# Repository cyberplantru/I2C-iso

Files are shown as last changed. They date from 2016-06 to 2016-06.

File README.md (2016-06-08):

EC Reader
##CyberPlant I2C *iso* Mini

The I2C *iso* Mini v3.0 are hot swappable digital isolators with nonlatching, bidirectional communication channels that
are compatible with I2C interfaces. This eliminates the need for
splitting I2C signals into separate transmit and receive signals
for use with standalone optocouplers. The I2C *iso* Mini provides two bidirectional channels, supporting a complete isolated I2C interface.

##Features:
- Regulated 3.3 V or 5 V output
- Up to 500 mW output power
- Bidirectional I2C communication
- input-output pull up 4k7
- Can use as Shield for Arduino Pro Mini
- PCB Size : 33.02 mm×17.78 mm

## Applications
- Isolated sensor interfaces
- Isolated I2C, SMBus, or PMBus interfaces
- Multilevel I2C interfaces
- Power supplies
- Networking
- RS-232/RS-422/RS-485 transceivers

#### Regulated 3.3 V or 5 V output

By default supply voltage set to output 5V. For use other mode need to cut copper wire on layer top and use jumper as switch

pH to I2C
 


## Isolation of sensors

Use to eliminate electrical noise. The I2Ciso recommended to when reading pH and Conductivity together. Compatible with [pH Mini](https://github.com/cyberplantru/pH-Mini-v30-sample-code) and [EC Mini](EC-Mini-v30-Sample-Code). 

pH to I2C

----------

### Package include:

-     1 x I2C iso Mini v3.0
-     2 x 12 PLS connectors
-     2 x 4 angle PLS
-     1 x jumper

----------

### Documentation:

- [Hardware](https://github.com/cyberplantru/I2C-iso/)
- [link to CyberPlant](http://www.cyber-plant.com).

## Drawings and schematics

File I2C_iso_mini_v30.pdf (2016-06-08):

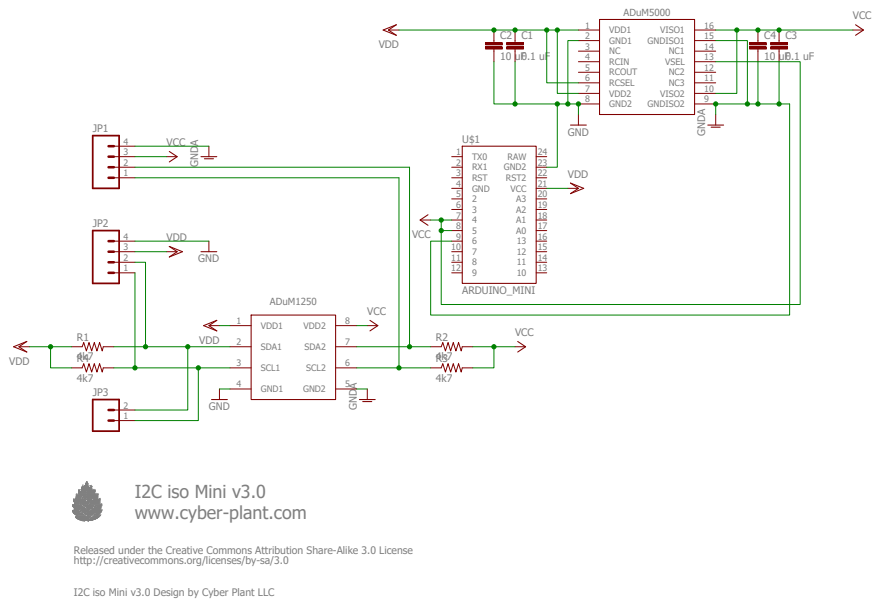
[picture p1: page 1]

I2C iso Mini v3.0
www.cyber-plant.com

Released under the Creative Commons Attribution Share-Alike 3.0 License
http://creativecommons.org/licenses/by-sa/3.0

I2C iso Mini v3.0 Design by Cyber Plant LLC

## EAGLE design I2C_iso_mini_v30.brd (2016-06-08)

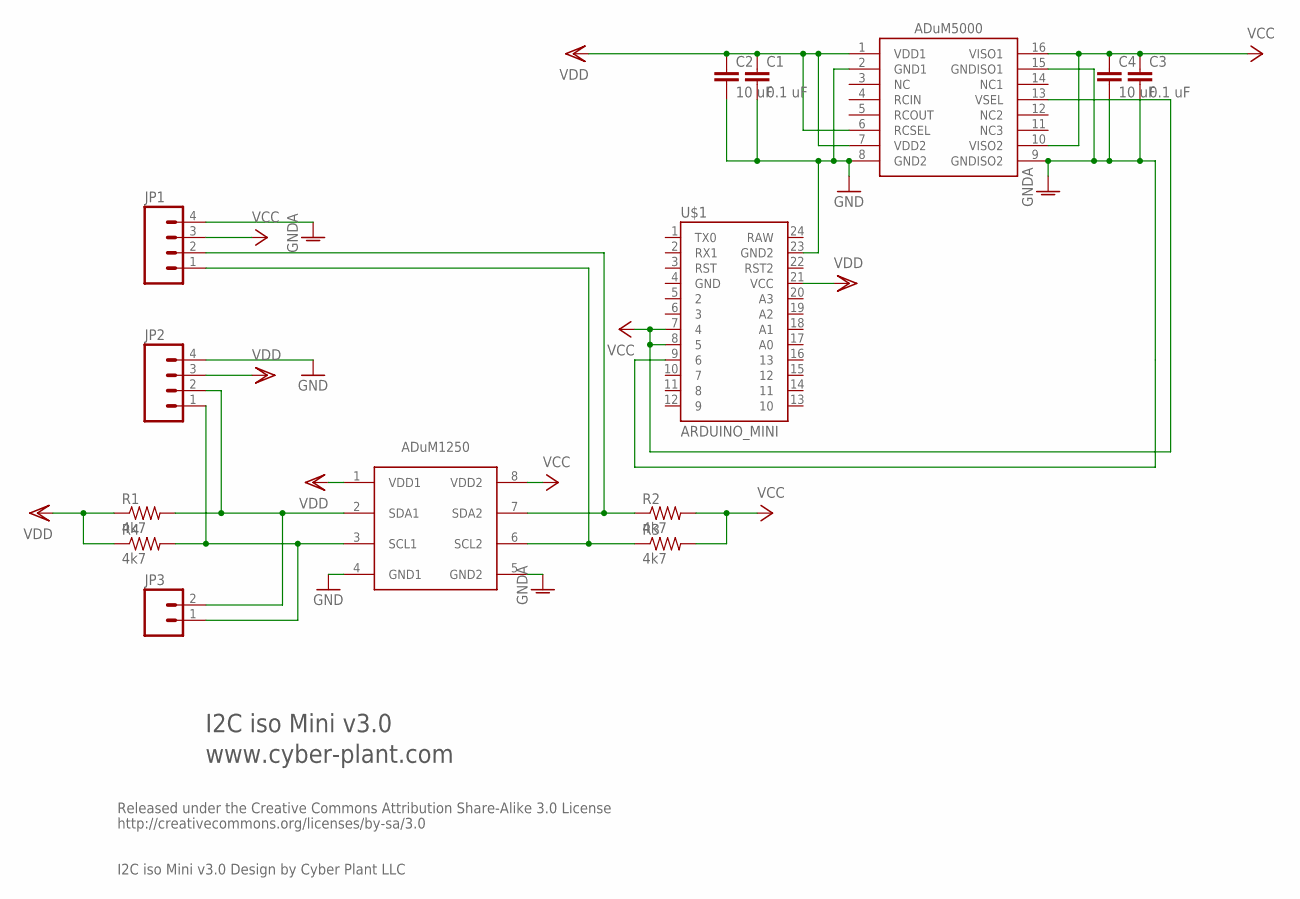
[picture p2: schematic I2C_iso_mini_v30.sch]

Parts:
C1, C3: 0.1 uF; 1206
C2, C4: 10 uF; 1206
JP1, JP2: M04PTH; 1X04
JP3: M02PTH; 1X02
R1, R2, R3, R4: 4k7; 1206
U$1: ARDUINO_MINI
U$3: ADUM1251; SO8
U$4: ADUM5000; SO-16W

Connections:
GND: C1.2, C2.2, JP2.4, U$1.23 (GND2), U$3.4 (GND1), U$4.2 (GND1), U$4.8 (GND2)
GNDA: C3.2, C4.2, JP1.4, U$1.9 (6), U$3.5 (GND2), U$4.9 (GNDISO2), U$4.15 (GNDISO1)
SCL: JP2.1, JP3.1, R4.2, U$3.3 (SCL1)
SCL2: JP1.1, R3.1, U$3.6 (SCL2)
SDA: JP2.2, JP3.2, R1.2, U$3.2 (SDA1)
SDA2: JP1.2, R2.1, U$3.7 (SDA2)
VCC: C3.1, C4.1, JP1.3, R2.2, R3.2, U$1.7 (4), U$1.8 (5), U$3.8 (VDD2), U$4.10 (VISO2), U$4.13 (VSEL), U$4.16 (VISO1)
VDD: C1.1, C2.1, JP2.3, R1.1, R4.1, U$1.21 (VCC), U$3.1 (VDD1), U$4.1 (VDD1), U$4.6 (RCSEL), U$4.7 (VDD2)

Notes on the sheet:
Released under the Creative Commons Attribution Share-Alike 3.0 License
http://creativecommons.org/licenses/by-sa/3.0
I2C iso Mini v3.0 Design by Cyber Plant LLC
I2C iso Mini v3.0
www.cyber-plant.com

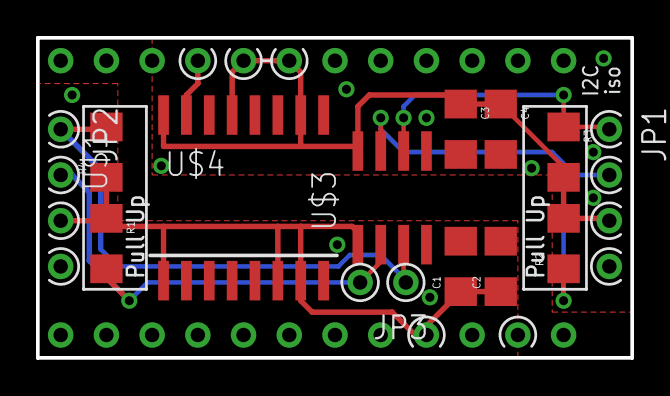
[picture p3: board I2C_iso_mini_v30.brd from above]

Board: 2 copper layers, 33.0 x 17.8 mm, 14 parts (0 on the bottom side), 8 nets.

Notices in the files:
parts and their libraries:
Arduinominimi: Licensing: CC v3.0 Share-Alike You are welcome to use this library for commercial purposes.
